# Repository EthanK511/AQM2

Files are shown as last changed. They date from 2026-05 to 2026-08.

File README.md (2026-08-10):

# AQM2
A portable, inexpensive, open source, low-power CO2/air quality monitor
Untitled drawing
[Oshwlab](https://oshwlab.com/eknorwegia/project_kpvsolpj)
[Easy Eda View Project](https://pro.easyeda.com/editor#id=3279f3b71d5047e581513a55c1dcb35e)
There are two versions of this device. The first version with the larger PCB shown above was the original version. This version turned out to be too expensive so I pivoted to a more cost-effective yet still really good version.
## Why
### AQM1
In 2024, I started my first iteration of this project (AQM). Back then, it was also called many other names, such as "like CO2 Cloud" and "Big Waste Of Money".
### AQM2
I wanted to start work on a second version because I had some issues with the first; the design could have used some improvement, and my coding skills are much better now.
#### Issues With AQM1
1. Big
2. Expensive
3. Connects with Dupont cables
4. High power consumption
5. Ugly Interface

I planned to fix all of these issues with the first version of AQM2, and for everything except the price, it was amazing. However, the $50 price tag for a single PCB was more than I wanted to spend. With the second version of AQM2, I fixed this and simplified the design a bunch, and relying on my soldering skills to assemble the PCBs in my garage. This allowed me to bring the cost down to just a few cents per PCB.
## How
All of these issues can be solved in 3 steps
1. Custom PCB
2. New Code
3. New Interface

The device works when the SCD 41 gets a reading of temperature, humidity, and CO2 levels from the air around it. It uses an SDA and SCD connection to transmit this data to the ESP. From there, the data is sent via Wi-Fi to a Firebase database and then forwarded to a webpage using some simple HTML.
## BOM

|No.|Quantity|Comment |Designator|Footprint |Value|Manufacturer Part|Manufacturer|Supplier Part|Supplier|
|---|---|---|---|---|-----|---|---|---|---|
|1  |2 |0.1uF |C1,C2 |C0603 |0.1uF| | | | |
|2  |1 |ESP32C3L|H1 |HDR-TH_7P-P2.54-V-M | |ESP32C3L |hanxia(韩下)  |C32713273 |LCSC |
|3  |1 |ESP32C3R|H2 |HDR-TH_7P-P2.54-V-M | |ESP32C3R |hanxia(韩下)  |C32713273 |LCSC |
|4  |1 |2.54-1*4|SCD41 |HDR-TH_4P-P2.54-V-M-1 | |2.54-1*4 |ZHOURI(洲日)  |C5116483 |LCSC |
|5  |2 |SK6812  |U1,U2 |LED-SMD_4P-L5.0-W5.0-LS5.4-TL-1| |SK6812 |欧思科光电 |C5378720 |LCSC |

|Mrf# |Mfr. |Order Qty.|Unit Price(USD)|Ext.Price(USD)|LCSC# |Package |Min|Mult|SPQ |Availability|Stock Status|Customer Notes|Description |Matched status|Product Link |
|---|---|---|---|---|---|---|---|----|----|---|---|---|---|---|---|
|SK6812 |OPSCO Optoelectronics |15 |0.0893 |$1.34 |C5378720|SMD-4P,5.4x5mm|5  |5 |1000|8695 |In Stock | |SMD-4P,5.4x5mm LED Addressable, Specialty RoHS|Exact Matches |https://www.lcsc.com/product-detail/C5378720.html|
|CL10B104KB8NNNC|Samsung Electro-Mechanics|100 |0.0160 |$1.60 |C1591 |0603 |100|100 |4000|2718200 |In Stock | |100nF ±10% 50V Ceramic Capacitor X7R 0603 |Exact Matches |https://www.lcsc.com/product-detail/C1591.html |
|JCLPCB |JCLPCB |20 |$3.33 |$6.00 | | | | | | | | | | | |
| | | | |$8.94 | | | | | | | | | | | |

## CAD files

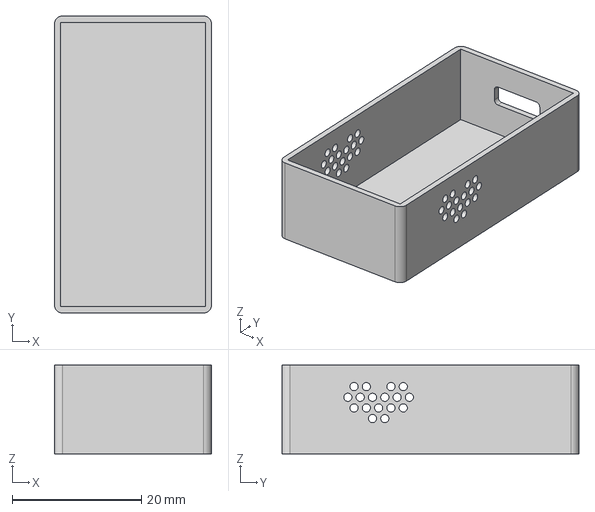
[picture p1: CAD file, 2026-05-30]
AQM2(V2)/CAD/Case/Case.step
24.4 x 46.0 x 13.7 mm

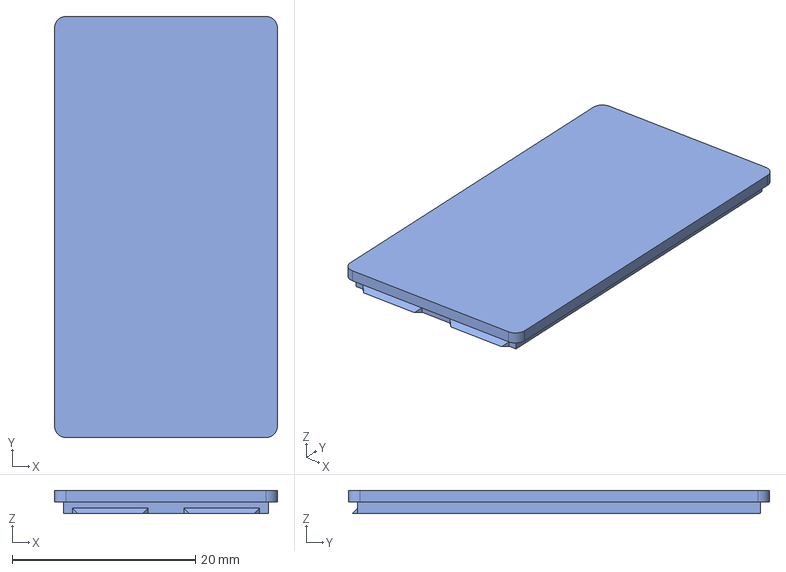
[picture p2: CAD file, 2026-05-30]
AQM2(V2)/CAD/Cover/Cover.step
24.4 x 46.0 x 2.54 mm

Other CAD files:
AQM2(V2)/CAD/Case/Case.3mf
AQM2(V2)/CAD/Case/Case.obj
AQM2(V2)/CAD/Case/Case.stl
AQM2(V2)/CAD/Cover/Cover.3mf
AQM2(V2)/CAD/Cover/Cover.obj
AQM2(V2)/CAD/Cover/Cover.stl

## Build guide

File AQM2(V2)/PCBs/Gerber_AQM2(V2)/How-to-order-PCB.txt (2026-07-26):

How to Order PCB

Please refer to:
https://prodocs.easyeda.com/en/pcb/order-order-pcb/index.html

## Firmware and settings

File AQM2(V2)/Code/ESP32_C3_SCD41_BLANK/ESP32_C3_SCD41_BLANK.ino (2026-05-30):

#include <WiFi.h>
#include <WiFiClientSecure.h>
#include <HTTPClient.h>
#include <ArduinoJson.h>
#include <Wire.h>
#include <SensirionI2cScd4x.h>
#include "time.h"

// User config
const char* WIFI_SSID     = "SSID";
const char* WIFI_PASSWORD = "PASS";

// Database info
const char* FIREBASE_HOST   = "HOST ADRESS";
const char* FIREBASE_SECRET = "DATABASE SECRET";
const char* DEVICE_ID       = "DEVICE NAME";

const uint64_t SLEEP_SECONDS = 300ULL;

const char* NTP_POOL = "pool.ntp.org";
const long  GMT_OFFSET_SEC = 0;
const int   DAYLIGHT_OFFSET_SEC = 0;

// timout setings
const unsigned long WIFI_CONNECT_TIMEOUT_MS   = 10000UL;
const unsigned long FIREBASE_HTTP_TIMEOUT_MS  = 8000UL;
const unsigned long NTP_SYNC_TIMEOUT_MS       = 4000UL;
const uint8_t       SCD4X_I2C_ADDRESS         = 0x62;
const uint8_t       SENSOR_INIT_RETRIES       = 3;
const uint8_t       SENSOR_DATA_ATTEMPTS      = 12;
const unsigned long SENSOR_POWERUP_DELAY_MS   = 1500;
const unsigned long SENSOR_READY_POLL_MS      = 1000;
const unsigned long SENSOR_FIRST_MEASUREMENT_DELAY_MS = 7000;

// SCD41 io pin config
const int I2C_SDA_PIN = 6;
const int I2C_SCL_PIN = 7;

// devices
SensirionI2cScd4x scd4x;
WiFiClientSecure wifiClientSecure;

unsigned long getUnixTime() {
  time_t now = 0;
  time(&now);
  if (now < 1600000000UL) return 0;
  return (unsigned long) now;
}

bool connectWiFi() {
  WiFi.mode(WIFI_STA);
  WiFi.begin(WIFI_SSID, WIFI_PASSWORD);
  unsigned long start = millis();
  while (WiFi.status() != WL_CONNECTED && millis() - start < WIFI_CONNECT_TIMEOUT_MS) {
    delay(200);
  }
  return (WiFi.status() == WL_CONNECTED);
}

bool sendToFirebase(uint16_t co2, float temperature, float humidity, unsigned long timestamp) {
  String url = String("https://") + FIREBASE_HOST + "/readings/" + DEVICE_ID + ".json?auth=" + FIREBASE_SECRET;

  StaticJsonDocument<256> doc;
  doc["co2"] = co2;
  doc["temperature"] = temperature;
  doc["humidity"] = humidity;
  doc["timestamp"] = timestamp;
  doc["status"] = "OK";
  String payload;
  serializeJson(doc, payload);

  wifiClientSecure.setInsecure();
  HTTPClient http;
  http.setTimeout(FIREBASE_HTTP_TIMEOUT_MS);
  if (!http.begin(wifiClientSecure, url)) {
    http.end();
    return false;
  }
  http.addHeader("Content-Type", "application/json");
  int httpCode = http.POST(payload);
  http.end();
  return (httpCode == HTTP_CODE_OK || httpCode == HTTP_CODE_CREATED || httpCode == HTTP_CODE_NO_CONTENT);
}

void logErrorToFirebase(const char* message) {
  if (WiFi.status() != WL_CONNECTED) return;
  String url = String("https://") + FIREBASE_HOST + "/errors/" + DEVICE_ID + ".json?auth=" + FIREBASE_SECRET;
  StaticJsonDocument<192> doc;
  doc["error"] = message;
  doc["timestamp"] = getUnixTime();
  String payload;
  serializeJson(doc, payload);

  wifiClientSecure.setInsecure();
  HTTPClient http;
  http.setTimeout(4000);
  if (http.begin(wifiClientSecure, url)) {
    http.addHeader("Content-Type", "application/json");
    http.POST(payload);
    http.end();
  }
}

void printWakeReason() {
  esp_sleep_wakeup_cause_t reason = esp_sleep_get_wakeup_cause();
  switch (reason) {
    case ESP_SLEEP_WAKEUP_TIMER: Serial.println("Wakeup reason: TIMER"); break;
    case ESP_SLEEP_WAKEUP_EXT0:  Serial.println("Wakeup reason: EXT0");  break;
    case ESP_SLEEP_WAKEUP_EXT1:  Serial.println("Wakeup reason: EXT1");  break;
    case ESP_SLEEP_WAKEUP_UNDEFINED: Serial.println("Wakeup reason: UNDEFINED/RESET"); break;
    default: Serial.printf("Wakeup reason: %d\n", (int)reason); break;
  }
}

void gotoDeepSleep() {
  scd4x.stopPeriodicMeasurement();
  WiFi.disconnect(true);
  WiFi.mode(WIFI_OFF);

  uint64_t sleep_us = (SLEEP_SECONDS == 0 ? 60ULL : SLEEP_SECONDS) * 1000000ULL;
  Serial.printf("Entering deep sleep for %llu seconds...\n", (unsigned long long)(sleep_us / 1000000ULL));
  esp_sleep_enable_timer_wakeup(sleep_us);
  delay(50);
  esp_deep_sleep_start();
}

void setup() {
  Serial.begin(115200);
  delay(50);
  Serial.println("\nBoot");
  printWakeReason();

  Wire.begin(I2C_SDA_PIN, I2C_SCL_PIN);
  delay(200);

  bool sensorReady = false;
  for (uint8_t i = 0; i < SENSOR_INIT_RETRIES; ++i) {
    scd4x.begin(Wire, SCD4X_I2C_ADDRESS);
    delay(SENSOR_POWERUP_DELAY_MS);

    scd4x.stopPeriodicMeasurement();
    delay(20);

    if (scd4x.startPeriodicMeasurement() == 0) {
      sensorReady = true;
      break;
    }
    delay(500 + i * 200);
  }

  if (!sensorReady) {
    Serial.println("SCD4x init failed, skipping read");
    logErrorToFirebase("Sensor init failed after wake");
    gotoDeepSleep();
    return;
  }

  delay(SENSOR_FIRST_MEASUREMENT_DELAY_MS);

  if (!connectWiFi()) {
    Serial.println("Wi-Fi connect failed");
    gotoDeepSleep();
    return;
  }

  Serial.print("Wi-Fi connected, IP: ");
  Serial.println(WiFi.localIP());

  configTime(GMT_OFFSET_SEC, DAYLIGHT_OFFSET_SEC, NTP_POOL);
  unsigned long ntpStart = millis();
  while (getUnixTime() == 0 && millis() - ntpStart < NTP_SYNC_TIMEOUT_MS) {
    delay(200);
  }

  bool readOk = false;
  for (uint8_t attempt = 0; attempt < SENSOR_DATA_ATTEMPTS; ++attempt) {
    bool ready = false;
    int16_t statusErr = scd4x.getDataReadyStatus(ready);
    if (statusErr == 0 && ready) {
      uint16_t co2;
      float temperature, humidity;
      if (scd4x.readMeasurement(co2, temperature, humidity) == 0) {
        unsigned long ts = getUnixTime();
        if (ts == 0) ts = millis() / 1000;
        Serial.printf("CO2: %u ppm | T: %.2f C | H: %.2f %% | ts: %lu\n", co2, temperature, humidity, ts);

        if (!sendToFirebase(co2, temperature, humidity, ts)) {
          Serial.println("Firebase send failed");
          logErrorToFirebase("Firebase send failed");
        }
        readOk = true;
        break;
      } else {
        Serial.println("Sensor readMeasurement error");
        logErrorToFirebase("Sensor readMeasurement error");
        delay(500);
      }
    } else {
      if (statusErr != 0) {
        Serial.printf("getDataReadyStatus error: %d\n", statusErr);
        logErrorToFirebase("getDataReadyStatus error");
      } else {
        Serial.println("Data not ready yet, waiting...");
      }
    }
    delay(SENSOR_READY_POLL_MS);
  }

  if (!readOk) logErrorToFirebase("Sensor read failed");

  gotoDeepSleep();
}

void loop() {
}

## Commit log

2026-05-30 Add cad files
    [Case.step, Cover.step]
2026-06-11 pcb info
    [BOM.csv, BOM.xlsx, Case.step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]
2026-06-11 Add onshape file formats
    [Case.3mf, Case.obj, Case.step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]
2026-07-26 Add cpl and gerber zip
    [Drill_NPTH_Through.DRL, Drill_PTH_Through.DRL, Drill_PTH_Through_Via.DRL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]
2026-08-07 Revise AQM1 issues and include BOM
    Updated issues section and added BOM details.
2026-08-10 Update README with device versions and components
    Added information about the two versions of the device and updated component details.
2026-10-16 Add journal entries for HackerCat project
    Documented the development process for the HackerCat wireless air-quality monitor, including part selection, PCB design, and firmware implementation.
2026-10-16 Revise journal entries and correct time logs
    Updated journal entries with corrected titles and total time spent for various project stages, including part selection, PCB schematic, and firmware development.
